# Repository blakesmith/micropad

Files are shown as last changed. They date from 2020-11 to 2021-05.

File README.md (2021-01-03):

# Micropad

This is a small macropad keyboard I built, mostly for controlling my music while working.

It includes:

- KiCAD schematic and PCB design.
- OpenSCAD case and top plate designs.
- Custom Rust firmware for the STM32F042 microcontroller
- Bill of materials, of all the components used.

License: MIT

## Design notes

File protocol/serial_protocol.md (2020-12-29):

# Micropad Serial Protocol

The micropad serial protocol is a simple byte-oriented format to
cotrol and configure the micropad from the connected host computer. It
uses a standard USB-CDC communication driver.

The first byte indicates the message type, followed by message
arguments. Successful responses return a 0 byte, error codes
non-zero. All message frames (requests and responses) are 8 byte aligned (64 bit frames).

Responses contain a response code in the first byte of the message
frame. Responses can also contain response arguments in the message
frame bytes, following the response code. The basic response codes
are:

0x00: Success.

0x80: Success, with a continuation bit set. The micropad will send
this response code when it has more response frames to send
callers. Callers continue to read message frames until either a
success response without the continuation bit set (0x00), or another
error value.

0x04: Not found.

## Message Types

### 0x01 - Ping

*Description*: Ping the micropad.
*Arguments*: No arguments.
*Valid responses*

- 0: Success

### 0x02 - Get Version

*Description*: Get the current firmware version
*Arguments*: No arguments.
*Valid responses*

- 0: Success, with follow on response bytes.
  - Byte 2: Major version. 0x00 - 0xFF.
  - Byte 3: Minor version. 0x00 - 0xFF.
  - Byte 4: Patch version. 0x00 - 0xFF.

### 0x03 - Set LED pulse brightness

*Description*: Set the LED pulse brightness when keys are pressed
*Arguments*: 1 byte brightness level.

- Arg 1: Brightness level. 0x00 - 0xFF.

*Valid responses*

- 0: Success

### 0x04 - Get the LED pulse brightness

*Description*: Retrieve the LED pulse brightness when the keys are pressed.
*Arguments*: No arguments.

*Valid responses*

- 0: Success, with follow on response bytes.
  - Byte 2: The current brightness level. 0x00 - 0xFF.

### 0x05 - Get current mode information

*Description*: Retrieve information about the mode.
*Arguments*: No arguments.
*Valid Responses*:

- 0: Success, with follow on response bytes.
  - Byte 2: Built in mode count.
  - Byte 3: User configurable mode count.
  - Byte 4: Current mode index. Enumeration starts at index 0, indexing the built-in modes first, followed by all the user modes. For example, if the built-in mode count is 2, and the user configurable mode count is 1, indices 0-1 would be built-in modes, and index 2 would be the user configurable mode.

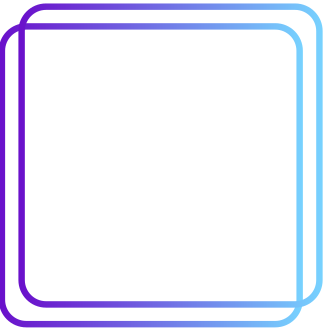
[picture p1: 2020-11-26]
square_only.png

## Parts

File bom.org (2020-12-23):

#+TITLE: Micropad Bill of Materials

| Name                              | Quantity | Part Number      | Price   | Link                                                                                                                                                                   |
|-----------------------------------+----------+------------------+---------+------------------------------------------------------------------------------------------------------------------------------------------------------------------------|
| STM32F042K6U6                     |        1 | C110616          | $2.72   | https://lcsc.com/product-detail/ST-Microelectronics_STMicroelectronics_STM32F042K6U6_STM32F042K6U6_C110616.html                                                        |
| 0603 2.5A fus                     |        1 | C311073          | $0.03   | https://lcsc.com/product-detail/Surface-Mount-Fuses_AEM_T0603HI3500TM_AEM-T0603HI3500TM_C311073.html                                                                   |
| Cherry MX Switches                |        3 |                  |         |                                                                                                                                                                        |
| LD1117-3.3                        |        1 | C347229          | $0.04   | https://lcsc.com/product-detail/Dropout-Regulators-LDO_UMW-Youtai-Semiconductor-Co-Ltd-LD1117-3-3_C347229.html                                                         |
| LED 0805                          |        2 | C601702          | $0.02   | https://lcsc.com/product-detail/Light-Emitting-Diodes-LED_TOGIALED-TJ-S2012CY8T5ALC6B-A5_C601702.html                                                                  |
| 100 ohm 0805                      |        2 | C17408           | $0.002  | https://lcsc.com/product-detail/Chip-Resistor-Surface-Mount_UNI-ROYAL-Uniroyal-Elec-0805W8F1000T5E_C17408.html                                                         |
| USB Micro B Connector             |        1 | C397452          | $0.02   | https://lcsc.com/product-detail/USB-Connectors_XKB-Connectivity-U254-051T-4BH83-F1S_C397452.html                                                                       |
| PEC11R-4015F-S0024 Rotary Encoder |        1 | C143789          | $1.78   | https://lcsc.com/product-detail/Coded-Rotary-Switches_BOURNS_PEC11R-4015F-S0024_PEC11R-4015F-S0024_C143789.html                                                        |
| 0.1uF SMD 0805 Cap                |        3 | C49678           | $0.0051 | https://lcsc.com/product-detail/Multilayer-Ceramic-Capacitors-MLCC-SMD-SMT_100nF-104-10-50V_C49678.html                                                                |
| 4.7uF SMD 0805 Cap                |        1 | C92762           | $0.026  | https://lcsc.com/product-detail/Multilayer-Ceramic-Capacitors-MLCC-SMD-SMT_TAIYO-YUDEN_EMK212B7475KG-T_4-7uF-475-10-16V_C92762.html                                    |
| 0.01uf SMD 0805 Cap               |        2 | C83170           | $0.0045 | https://lcsc.com/product-detail/Multilayer-Ceramic-Capacitors-MLCC-SMD-SMT_10nF-103-10-50V_C83170.html                                                                 |
| 10k 0805 Resistor                 |        5 | C115295          | $0.0015 | https://lcsc.com/product-detail/Chip-Resistor-Surface-Mount_FH-Guangdong-Fenghua-Advanced-Tech-RS-05K103JT_C115295.html                                                |
| 5.1k 0805 Resistor                |        2 | 311-5.10KCRCT-ND | $0.10   | https://www.digikey.com/en/products/detail/yageo/RC0805FR-075K1L/727988                                                                                                |
| APA102 DotStar RGB LED            |        1 | 2343             | $0.45   | https://www.digikey.com/en/products/detail/adafruit-industries-llc/2343/5761204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                                             |
| Encoder Knob                      |        1 | 1568-1600-ND     | $1.50   | https://www.digikey.com/en/products/detail/sparkfun-electronics/COM-10001/7229870                                                                                      |
| M3 8mm length standoff            |        4 | 732-12828-ND     | $0.40   | https://www.amazon.com/100Pcs-Female-Threaded-Standoff-Spacer/dp/B071VLNK37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          |
| M3 5mm male-female standoff       |        4 |                  |         | https://www.amazon.com/Antrader-Female-Thread-Standoff-100-Pack/dp/B07K67LVFR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 |
| USB-C Connector                   |        1 | WM12856CT-ND     | $2.19   | https://www.digikey.com/en/products/detail/molex/1054500101/5843890                                                                                                    |
|-----------------------------------+----------+------------------+---------+------------------------------------------------------------------------------------------------------------------------------------------------------------------------|

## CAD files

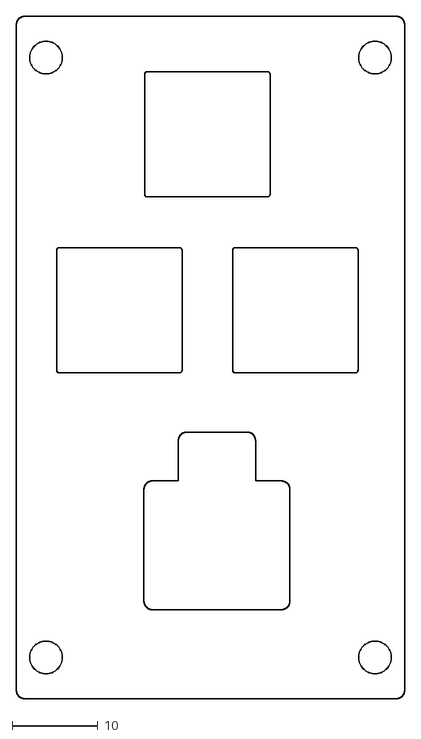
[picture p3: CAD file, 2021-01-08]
hardware/top_plate.dxf
45.2 x 79.5

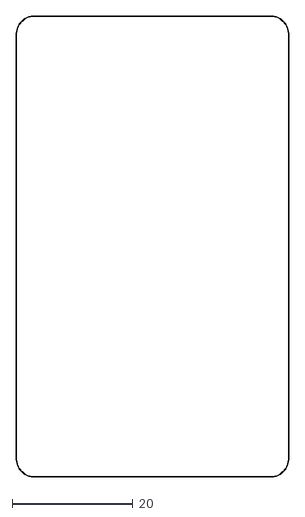
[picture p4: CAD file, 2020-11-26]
hardware/board_outline.dxf
45.1 x 76.5

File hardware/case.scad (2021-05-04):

$fn = 100;

module actual_pcb_board_outline() {
    rotate(a=180) {
        translate([0, 0])
            linear_extrude(height=10)
            import(file = "micropad/micropad-brd.svg", center=true);
    }
}

//actual_pcb_board_outline();

total_1u_count = 2;
row_count = 2;

switch_cutout_1u_width = 14.0;
switch_cutout_1u_length = 14.0;
switch_cutout_1u_padding = 6.50;
switch_cutout_1u_pitch = switch_cutout_1u_width + switch_cutout_1u_padding;

top_plate_padding_top_bottom = 0;
top_plate_padding_left_right = 0;
top_plate_height = 1.5;
top_plate_width = (((row_count * switch_cutout_1u_pitch) + top_plate_padding_top_bottom) * 1.854) + 1.5;
top_plate_length = (((total_1u_count * switch_cutout_1u_pitch) + top_plate_padding_left_right) * 1.03) + 1.0;
top_plate_corner_radius = 3;

echo("Top plate dimensions are w=", top_plate_width, ",l=", top_plate_length);

cherry_top_height = 3.6;
cherry_middle_height = 6.6;
cherry_bottom_width = 15.6;
cherry_bottom_length = 15.6;

dsa_keycap_bottom_width = 18.415;
dsa_keycap_bottom_length = 18.415;
dsa_keycap_top_length = 12.7;
dsa_keycap_top_width = 12.7;
dsa_keycap_height = 7.39;

encoder_width = 13;
encoder_length = 15;

encoder_base_height = 6.75;
encoder_shaft_height = 15.591;
encoder_shaft_diameter = 6.0;

apa102_length = 7;
apa102_width = 5;

usb_width = 9;
usb_length = 10.1;
usb_height = 4.56;

mounting_hole_radius = 1.5 + 0.4;
mounting_hole_head_radius = mounting_hole_radius + 0.8;
mounting_hole_head_height = 1.72;

mounting_hole_x_offset = 67.87 / 2; // Measured from the PCB directly
mounting_hole_y_offset = 36.33 / 2; // Measured form the PCB directly

pcb_width = 76.4;
pcb_length = 45.13;
pcb_height = 1.6;

standoff_radius = 2;
standoff_height = 8;

plate_standoff_radius = 2;
plate_standoff_height = 5;

case_chamfer_size = 2;
case_wall_thickness = 2;
case_length = pcb_length;
case_width = pcb_width + 3.2;

case_height = standoff_height + pcb_height + top_plate_height + (case_wall_thickness / 2) + plate_standoff_height - (case_chamfer_size / 2) + 5;

echo("Case height is: ", case_height);

standoff_offset_z = (case_height / 2) - (case_wall_thickness / 2);
pcb_offset_z = -standoff_offset_z + standoff_height;
plate_standoff_offset_z = pcb_offset_z + pcb_height;
top_plate_offset_z = plate_standoff_offset_z + plate_standoff_height;

echo("Top plate PCB distance is: ", top_plate_offset_z - pcb_offset_z);

encoder_offset_x = 0;
encoder_offset_y = -(top_plate_width / 2 / 2);
encoder_offset_z = pcb_offset_z + (encoder_base_height / 2) + pcb_height;

knob_radius = 12;
knob_height = 14;

MUTE_PALLETTE = [
    [39, 86, 123],
    [182, 59, 59],
    [249, 196, 20]
];

KEYCAP_PALLETTE = MUTE_PALLETTE;

C1 = [KEYCAP_PALLETTE[0][0] / 255, KEYCAP_PALLETTE[0][1] / 255, KEYCAP_PALLETTE[0][2] / 255];
C2 = [KEYCAP_PALLETTE[1][0] / 255, KEYCAP_PALLETTE[1][1] / 255, KEYCAP_PALLETTE[1][2] / 255];
C3 = [KEYCAP_PALLETTE[2][0] / 255, KEYCAP_PALLETTE[2][1] / 255, KEYCAP_PALLETTE[2][2] / 255];

KEYCAP_COLORS = [
    [C1, C1],
    [C1, C1],
];

union() {
//    pcb();
//    top_plate(top_plate_height);
    case();
//    plate(top_plate_length, top_plate_width, top_plate_corner_radius);
}

module pcb() {
    color("green") {
        translate([0, 0, pcb_offset_z]) {
            linear_extrude(height=pcb_height) {
                difference() {
                    plate(top_plate_length, top_plate_width, 0);
                    mounting_holes();
                }
            }
        }
    }
}

module top_plate(height=0) {
    translate([0, 0, top_plate_offset_z]) {
//        linear_extrude(height=height) {
            difference() {
                plate(top_plate_length, top_plate_width);
                union() {
                    translate([0.75, -2.5]) {
                        row_0_switch_cutout();
                        row_1_switch_cutout();
                        encoder_cutout();
                        apa102_cutout();
                    }
                    mounting_holes();
                }
            }
//        }
    }
}

module case() {
    module main_cutout() {
        translate([0, 0, case_wall_thickness]) {
            hull() {
                cube([case_length - case_wall_thickness,
                      case_width - case_wall_thickness,
                      case_height - case_wall_thickness], center=true);
                3d_rounded_corners(length=case_length - case_wall_thickness - (case_chamfer_size / 2),
                                   width=case_width - case_wall_thickness - (case_chamfer_size / 2),
                                   height=case_height - case_wall_thickness, corner_radius=2);
            }
        }
    }

    module usb_case_cutout() {
        height = usb_height + 3.0;
        translate([0, -(top_plate_width / 2) - 5, pcb_offset_z + (height / 2) + (pcb_height + 0.2)]) {
            hull() {
                cube([usb_length, usb_width, height], center=true);
                3d_rounded_corners(usb_length, usb_width, height, corner_radius=1);
            }
        }
    }

    difference() {
        //color("cyan")
            hull() {
                cube([case_length, case_width, case_height], center=true);
                3d_rounded_corners(length=case_length, width=case_width, height=case_height - case_chamfer_size, corner_radius=2);
            }
        union() {
            main_cutout();
            usb_case_cutout();
            translate([0, 0, -(case_height / 2) - 0.1]) {
                linear_extrude(height = mounting_hole_head_height) {
                    mounting_holes(radius = mounting_hole_head_radius);
                }
            }
            translate([0, 0, -(case_height / 2) - (standoff_height / 3)]) {
                linear_extrude(height = standoff_height * 2) {
                    mounting_holes(radius = mounting_hole_radius);
                }
            }
        }
    }
//    standoffs();
//    encoder();
}

module encoder() {
    top_of_encoder_base = encoder_offset_z + (encoder_base_height / 2);
    encoder_shaft_height_offset = top_of_encoder_base + (encoder_shaft_height / 2);

    module encoder_base() {
        translate([0, 0, encoder_offset_z]) {
            color("red")
                rotate(90)
                cube([encoder_width,
                      encoder_length,
                      encoder_base_height],
                     center=true);
        }
    }

    module encoder_shaft() {
        translate([0, 0, encoder_shaft_height_offset]) {
            color("blue")
                cylinder(h=encoder_shaft_height,
                         d=encoder_shaft_diameter,
                         center=true);
        }
    }

    module knob() {
        translate([0, 0, encoder_shaft_height_offset - (knob_height / 3)]) {
            color("silver")
                cylinder(r=knob_radius, h=knob_height);
        }
    }

    translate([0, encoder_offset_y]) {
        encoder_base();
        encoder_shaft();
        knob();
    }
}

module encoder_cutout() {
    translate([0, encoder_offset_y])
        hull() {
        square([encoder_length+2, encoder_width], center=true);
        rounded_corners(encoder_length, encoder_width, 1);
    }
}

module apa102_cutout() {
    translate([0, -(top_plate_width / 2 / 2 / 2)])
        hull() {
        square([apa102_length, apa102_width], center=true);
        rounded_corners(apa102_length, apa102_width, 1);
    }
}

module standoffs() {
    // Lower standoff
    translate([0, 0, -standoff_offset_z]) {
        translate([-mounting_hole_y_offset, -mounting_hole_x_offset])
            cylinder(r=standoff_radius, h=standoff_height);
        translate([mounting_hole_y_offset, -mounting_hole_x_offset])
            cylinder(r=standoff_radius, h=standoff_height);
        translate([mounting_hole_y_offset, mounting_hole_x_offset])
            cylinder(r=standoff_radius, h=standoff_height);
        translate([-mounting_hole_y_offset, mounting_hole_x_offset])
            cylinder(r=standoff_radius, h=standoff_height);
    }

    // Middle standoff
    translate([0, 0, plate_standoff_offset_z]) {
        translate([-mounting_hole_y_offset, -mounting_hole_x_offset])
            cylinder(r=plate_standoff_radius, h=plate_standoff_height);
        translate([mounting_hole_y_offset, -mounting_hole_x_offset])
            cylinder(r=plate_standoff_radius, h=plate_standoff_height);
        translate([mounting_hole_y_offset, mounting_hole_x_offset])
            cylinder(r=plate_standoff_radius, h=plate_standoff_height);
        translate([-mounting_hole_y_offset, mounting_hole_x_offset])
            cylinder(r=plate_standoff_radius, h=plate_standoff_height);
    }
}
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

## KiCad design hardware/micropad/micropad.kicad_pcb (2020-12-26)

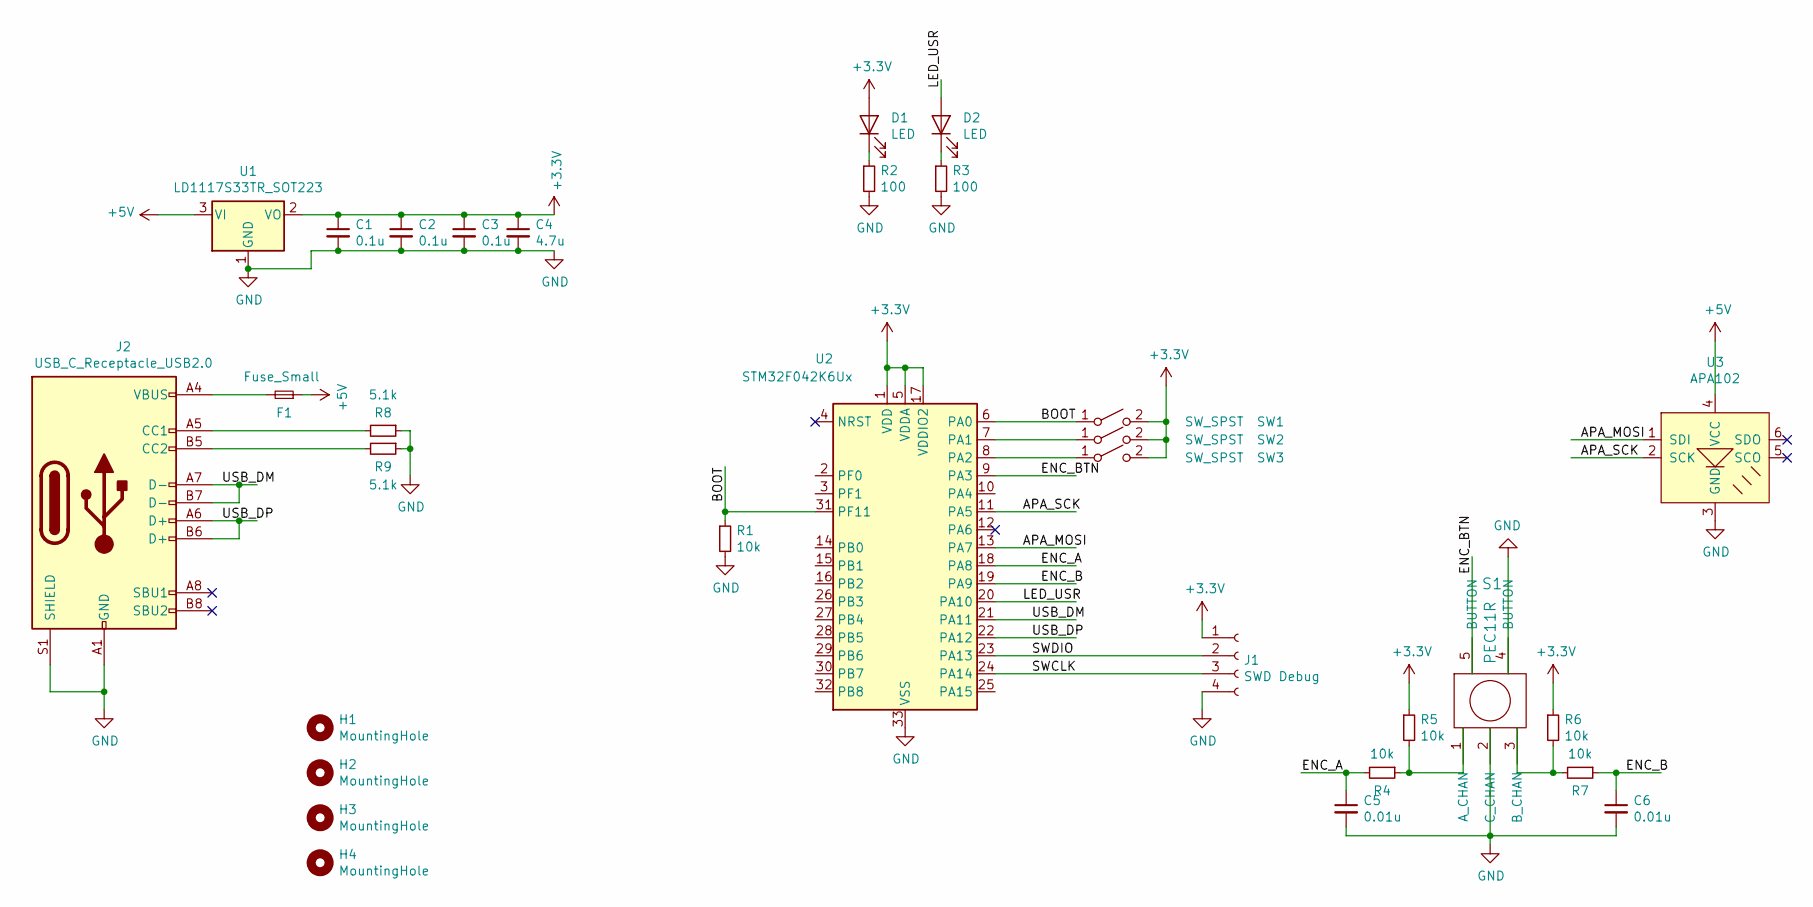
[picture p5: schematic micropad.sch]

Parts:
C1, C2, C3: 0.1u; C_0805
C4: 4.7u; C_0805
C5, C6: 0.01u; C_0805
D1, D2: LED; LED_0805
F1: Fuse_Small; C_0603
H1, H2, H3, H4: MountingHole; MountingHole_3.2mm_M3_ISO7380_Pad
J1: SWD Debug; REDFIT_IDC_SKEDD_CONN_4PIN
J2: USB_C_Receptacle_USB2.0; USB_C_Receptacle_Molex_1054500101
R1, R4, R5, R6, R7: 10k; R_0805
R2, R3: 100; R_0805
R8, R9: 5.1k; R_0805
S1: PEC11R; PEC11
SW1: SW_SPST; SW_Cherry_MX1A_2.00u_Plate
SW2, SW3: SW_SPST; SW_Cherry_MX1A_1.00u_Plate
U1: LD1117S33TR_SOT223; SOT-223
U2: STM32F042K6Ux; QFN-32-1EP_5x5mm_Pitch0.5mm
U3: APA102; LED_RGB_5050-6

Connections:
+3V3: C1.1, C2.1, C3.1, C4.1, D1.2 (A), J1.1, R5.1, R6.1, SW1.2 (B), SW2.2 (B), SW3.2 (B), U1.2 (VO), U2.1 (VDD), U2.5 (VDDA), U2.17 (VDDIO2)
+5V: F1.1, U1.3 (VI), U3.4 (VCC)
/APA_MOSI: U2.13 (PA7), U3.1 (SDI)
/APA_SCK: U2.11 (PA5), U3.2 (SCK)
/BOOT: R1.1, SW1.1 (A), U2.6 (PA0), U2.31 (PF11)
/ENC_A: C5.1, R4.2, U2.18 (PA8)
/ENC_B: C6.1, R7.1, U2.19 (PA9)
/ENC_BTN: S1.5 (BUTTON), U2.9 (PA3)
/LED_USR: D2.2 (A), U2.20 (PA10)
/SWCLK: J1.3, U2.24 (PA14)
/SWDIO: J1.2, U2.23 (PA13)
/USB_DM: J2.A7 (D-), J2.B7 (D-), U2.21 (PA11)
/USB_DP: J2.A6 (D+), J2.B6 (D+), U2.22 (PA12)
GND: C1.2, C2.2, C3.2, C4.2, C5.2, C6.2, J1.4, J2.A1 (GND), J2.A12 (GND), J2.B1 (GND), J2.B12 (GND), J2.S1 (SHIELD), R1.2, R2.2, R3.2, R8.1, R9.1, S1.2 (C_CHAN), S1.4 (BUTTON), U1.1 (GND), U2.33 (VSS), U3.3 (GND)
unnamed: D1.1 (K), R2.1
unnamed: D2.1 (K), R3.1
unnamed: F1.2, J2.A4 (VBUS), J2.A9 (VBUS), J2.B4 (VBUS), J2.B9 (VBUS)
unnamed: J2.A5 (CC1), R8.2
unnamed: J2.B5 (CC2), R9.2
unnamed: R4.1, R5.2, S1.1 (A_CHAN)
unnamed: R6.2, R7.2, S1.3 (B_CHAN)
unnamed: SW2.1 (A), U2.7 (PA1)
unnamed: SW3.1 (A), U2.8 (PA2)

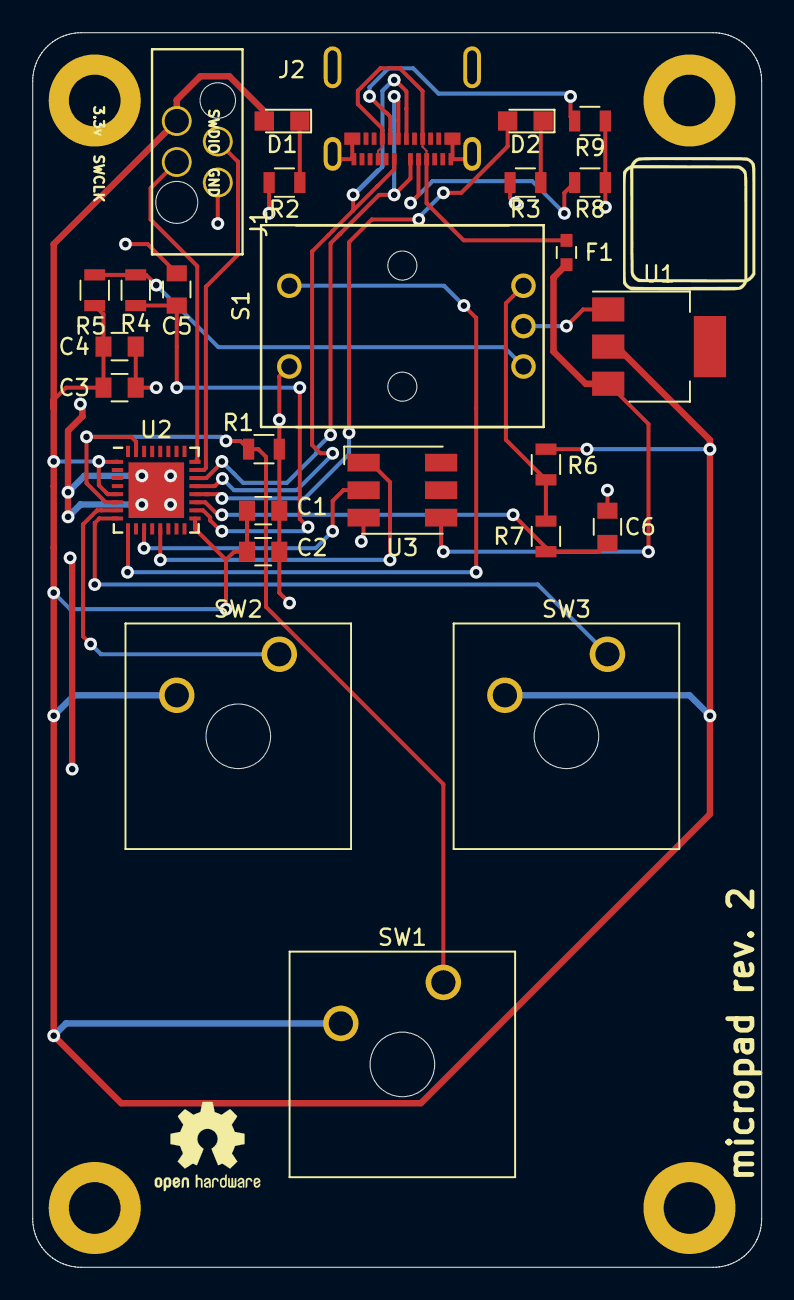
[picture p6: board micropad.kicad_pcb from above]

Board: 2 copper layers, 45.1 x 76.5 mm, 31 parts (0 on the bottom side), 23 nets.

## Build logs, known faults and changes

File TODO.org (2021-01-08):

#+TITLE: Micropad Todo List

* DONE Design CNC case
** DONE Add in tolerance for tallest PCB component?
* DONE Validate encoder shaft diameter
* DONE Replace JTAG connector with pin header holes
  - 4-pin connector: https://www.digikey.com/en/products/detail/w-rth-elektronik/490107670412/7917216
* DONE Validate mounting hole sizes
* DONE Name and logo
* DONE Research black magic probe and connectors
* DONE Validate boot pin button
* DONE Order boards and components
* DONE Test top plate fitting
* DONE Order top plate
* DONE Order 3D printed / CNC case
* DONE Update PCB to USB-C
** DONE Case cutout
* DONE Add additional ground connections to stm32
* DONE Change to M3 mounting holes
** DONE Case
** DONE PCB
* DONE Solve top plate spacing issue
  - 5mm bottom switch to plate height, 1.5mm top plate thickness
** TODO Case height
* DONE Order rev. 2 components 
  - USB C connectors
  - 5.1k resistors
  - Gateron blues
* DONE Order rev. 2 of PCBs (gold plating!)
** DONE Double check mounting hole alignment
* DONE DFU firmware update prototype
* DONE Multiple modes
* DONE Order rev. 2 of case and top plate
* DONE Order keycaps
* TODO Easy, in the field DFU updates?

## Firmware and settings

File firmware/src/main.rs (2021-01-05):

#![no_main]
#![no_std]

pub mod encoder;
pub mod hid;

use apa102_spi::{Apa102, PixelOrder};
use embedded_hal::serial::{Read, Write};
use encoder::RotaryEncoder;
use micropad_protocol::{Message, MessageFrame, ResponseCode, ResponsePayload};
use smart_leds::{gamma, SmartLedsWrite};
use smart_leds_trait::RGB8;

use panic_halt as _;

use stm32f0xx_hal as hal;

use hal::{
    delay::Delay,
    gpio::{
        gpioa::{PA0, PA1, PA10, PA2, PA3, PA5, PA6, PA7, PA8, PA9},
        Alternate, Floating, Input, Output, PullDown, PullUp, PushPull, AF0,
    },
    pac,
    pac::{interrupt, Interrupt},
    prelude::*,
    spi,
    usb::UsbBus,
};

use usb_device::bus::UsbBusAllocator;
use usb_device::prelude::*;
use usbd_serial::SerialPort;

use core::{cell::RefCell, ops::DerefMut};
use cortex_m::{interrupt::free as disable_interrupts, interrupt::Mutex, peripheral::NVIC};
use cortex_m_rt::entry;

use crate::hid::{Key, KeyboardHidClass, MediaCode, ScanCode};

const MAJOR_VERSION: u8 = 0;
const MINOR_VERSION: u8 = 1;
const PATCH_VERSION: u8 = 0;

static mut USB_BUS_ALLOC: Option<UsbBusAllocator<UsbBus<hal::usb::Peripheral>>> = None;
static USB_DEV: Mutex<RefCell<Option<UsbDevice<UsbBus<hal::usb::Peripheral>>>>> =
    Mutex::new(RefCell::new(None));
static USB_KEYBOARD: Mutex<RefCell<Option<KeyboardHidClass<UsbBus<hal::usb::Peripheral>>>>> =
    Mutex::new(RefCell::new(None));
static USB_SERIAL: Mutex<RefCell<Option<SerialPort<UsbBus<hal::usb::Peripheral>>>>> =
    Mutex::new(RefCell::new(None));

type Mode = [Key; 5];

static MUSIC_MODE: Mode = [
    Key::Media(MediaCode::VolumeUp),
    Key::Media(MediaCode::VolumeDown),
    Key::Media(MediaCode::PlayPause),
    Key::Media(MediaCode::ScanNext),
    Key::Media(MediaCode::ScanPrev),
];

static NAV_MODE: Mode = [
    Key::Normal(ScanCode::DownArrow),
    Key::Normal(ScanCode::UpArrow),
    Key::Normal(ScanCode::Return),
    Key::Normal(ScanCode::RightArrow),
    Key::Normal(ScanCode::LeftArrow),
];

static MODES: [&'static Mode; 2] = [&MUSIC_MODE, &NAV_MODE];

static CONTROL_STATE: Mutex<RefCell<ControlState>> = Mutex::new(RefCell::new(ControlState {
    led_brightness: 127,
    mode_index: 0,
}));

struct Devices {
    ok_led: PA10<Output<PushPull>>,
    delay: Delay,
    play_pause: PA0<Input<PullDown>>,
    next: PA2<Input<PullDown>>,
    prev: PA1<Input<PullDown>>,
    enc_btn: PA3<Input<PullUp>>,
    apa102: Apa102<
        spi::Spi<
            hal::stm32::SPI1,
            PA5<Alternate<AF0>>,
            PA6<Alternate<AF0>>,
            PA7<Alternate<AF0>>,
            spi::EightBit,
        >,
    >,
    encoder: RotaryEncoder<PA8<Input<Floating>>, PA9<Input<Floating>>>,
}

#[derive(Clone)]
struct ControlState {
    led_brightness: u8,
    mode_index: u8,
}

impl ControlState {
    fn set_led_brightness(&mut self, brightness: u8) {
        self.led_brightness = brightness;
    }

    fn get_led_brightness(&self) -> u8 {
        self.led_brightness
    }

    fn next_mode(&mut self) {
        self.mode_index = (self.mode_index + 1) % MODES.len() as u8;
    }

    fn get_mode_index(&self) -> u8 {
        self.mode_index
    }

    fn get_mode(&self) -> &'static Mode {
        MODES[self.mode_index as usize]
    }
}

struct LEDIndicatorState {
    color: RGB8,
    phase: u16,
}

impl LEDIndicatorState {
    fn new() -> Self {
        Self {
            color: RGB8 { r: 0, g: 0, b: 0 },
            phase: 0,
        }
    }

    fn pulse_color(&mut self, color: RGB8, brightness: u8) {
        self.color = color;
        self.phase = (brightness as u16) << 8;
    }

    fn write_if_blinking(
        &mut self,
        apa102: &mut Apa102<
            spi::Spi<
                hal::stm32::SPI1,
                PA5<Alternate<AF0>>,
                PA6<Alternate<AF0>>,
                PA7<Alternate<AF0>>,
                spi::EightBit,
            >,
        >,
    ) {
        if self.phase > 0 {
            self.phase -= 10;
            if self.color.r != 0 {
                self.color.r = (self.phase >> 8) as u8;
            };
            if self.color.g != 0 {
                self.color.g = (self.phase >> 8) as u8;
            };
            if self.color.b != 0 {
                self.color.b = (self.phase >> 8) as u8;
            };
            apa102.write(gamma([self.color].iter().cloned())).unwrap();
        }
    }
}

fn setup() -> Devices {
    let mut peripherals = pac::Peripherals::take().unwrap();
    let mut core = pac::CorePeripherals::take().unwrap();
    disable_interrupts(|cs| {
        let mut rcc = peripherals
            .RCC
            .configure()
            .hsi48()
            .enable_crs(peripherals.CRS)
            .sysclk(48.mhz())
            .pclk(24.mhz())
            .freeze(&mut peripherals.FLASH);

        let gpioa = peripherals.GPIOA.split(&mut rcc);
        let (
            play_pause,
            prev,
            next,
            enc_btn,
            enc_cw,
            enc_ccw,
            mut ok_led,
            sck,
            miso,
            mosi,
            usb_dm,
            usb_dp,
        ) = (
            gpioa.pa0.into_pull_down_input(cs), // Play pause button, has a 10k pull down resistor on the board
            gpioa.pa1.into_pull_down_input(cs), // Next button
            gpioa.pa2.into_pull_down_input(cs), // Prev button
            gpioa.pa3.into_pull_up_input(cs),   // Encoder button
            gpioa.pa8.into_floating_input(cs), // Encoder A, has a 10k pull up resistor on the board
            gpioa.pa9.into_floating_input(cs), // Encoder B, has a 10k pull up resistor on the board
            gpioa.pa10.into_push_pull_output(cs), // LED usr
            gpioa.pa5.into_alternate_af0(cs),  // APA102 SPI SCK
            gpioa.pa6.into_alternate_af0(cs),  // APA102 SPI MISO
            gpioa.pa7.into_alternate_af0(cs),  // APA102 SPI MOSI
            gpioa.pa11,                        // USB dm
            gpioa.pa12,                        // USB dp
        );
        let delay = Delay::new(core.SYST, &rcc);
        let spi = spi::Spi::spi1(
            peripherals.SPI1,
            (sck, miso, mosi),
            spi::Mode {
                polarity: spi::Polarity::IdleLow,
                phase: spi::Phase::CaptureOnFirstTransition,
            },
            1.mhz(),
            &mut rcc,
        );
        let apa102 = Apa102::new_with_options(spi, 4, true, PixelOrder::RBG);
        let encoder = RotaryEncoder::new(enc_cw, enc_ccw);
        let usb = hal::usb::Peripheral {
            usb: peripherals.USB,
            pin_dm: usb_dm,
            pin_dp: usb_dp,
        };

        unsafe {
            let bus_allocator = {
                USB_BUS_ALLOC = Some(UsbBus::new(usb));
                USB_BUS_ALLOC.as_ref().unwrap()
            };
            *USB_KEYBOARD.borrow(cs).borrow_mut() = Some(KeyboardHidClass::new(&bus_allocator));
            *USB_SERIAL.borrow(cs).borrow_mut() = Some(SerialPort::new(&bus_allocator));
            *USB_DEV.borrow(cs).borrow_mut() = Some(
                UsbDeviceBuilder::new(&bus_allocator, UsbVidPid(0xb38, 0x0003))
                    .manufacturer("micropad")
                    .product("micropad")
                    .serial_number("MP00X")
                    .max_packet_size_0(64)
                    .build(),
            );

            core.NVIC.set_priority(Interrupt::USB, 1);
            NVIC::unmask(Interrupt::USB);
        }

        ok_led.set_high().ok();
        Devices {
            ok_led,
            delay,
            play_pause,
            next,
            prev,
            enc_btn,
            apa102,
            encoder,
        }
    })
}

#[entry]
fn main() -> ! {
    let mut devices = setup();

    let led_color_reset: [RGB8; 1] = [RGB8 { r: 0, g: 0, b: 0 }];
    devices
        .apa102
        .write(led_color_reset.iter().cloned())
        .unwrap();

    let mut led_indicator = LEDIndicatorState::new();
    let mut current_encoder_count = 0;
    let mut key: Option<Key> = None;

    loop {
        let control_state = disable_interrupts(|cs| CONTROL_STATE.borrow(cs).borrow().clone());
        let current_mode = control_state.get_mode();

        // Sample encoder
        let encoder_sample: i32 = devices.encoder.read_count();
        let encoder_diff: i32 = encoder_sample - current_encoder_count;
        current_encoder_count = encoder_sample;

        // Encoder
        if encoder_diff > 0 {
            led_indicator.pulse_color(
                RGB8 {
                    r: 0,
                    b: 255,
                    g: 255,
                },
                control_state.get_led_brightness(),
            );
            key = Some(current_mode[0]);
        } else if encoder_diff < 0 {
            led_indicator.pulse_color(
                RGB8 {
                    r: 255,
                    b: 255,
                    g: 0,
                },
                control_state.get_led_brightness(),
            );
            key = Some(current_mode[1]);
        }
        // Buttons
        else if devices.play_pause.is_high().unwrap() {
            led_indicator.pulse_color(
                RGB8 { r: 0, g: 0, b: 255 },
                control_state.get_led_brightness(),
            );
            key = Some(current_mode[2]);
        } else if devices.next.is_high().unwrap() {
            led_indicator.pulse_color(
                RGB8 { r: 0, g: 255, b: 0 },
                control_state.get_led_brightness(),
            );
            key = Some(current_mode[3]);
        } else if devices.prev.is_high().unwrap() {
            led_indicator.pulse_color(
                RGB8 { r: 255, g: 0, b: 0 },
                control_state.get_led_brightness(),
            );
            key = Some(current_mode[4]);
        } else if devices.enc_btn.is_low().unwrap() {
            led_indicator.pulse_color(
                RGB8 {
                    r: 255,
                    g: 255,
                    b: 0,
                },
                control_state.get_led_brightness(),
            );
            key = None; // Switching modes, don't send a HID report.
            disable_interrupts(|cs| {
                CONTROL_STATE.borrow(cs).borrow_mut().next_mode();
            });
        } else {
            // Encoder diff is zero, and no buttons currently pressed. Reset report.
            key = None;
        }

        disable_interrupts(|cs| {
            if let &mut Some(ref mut keyboard) = USB_KEYBOARD.borrow(cs).borrow_mut().deref_mut() {
                match key {
                    Some(k) => keyboard.add_key(k),
                    None => keyboard.reset_report(),
                };

                keyboard.send_media_report_if_changed();
                keyboard.send_key_report_if_changed();
            }
        });

        led_indicator.write_if_blinking(&mut devices.apa102);

        // Make sure we delay outside of our 'disable_interrupts' block
        if key.is_some() {
            devices.delay.delay_ms(10u32);
        }
    }
}

fn read_into_frame<R>(frame: &mut MessageFrame, reader: &mut R) -> nb::Result<(), R::Error>
where
    R: Read<u8>,
{
    for i in 0..frame.frame_size() {
        match reader.read() {
            Ok(b) => frame.buf[i] = b,
            Err(err) => return Err(err),
        }
    }

    Ok(())
}

fn write_response<W>(
    frame: &mut MessageFrame,
    writer: &mut W,
    code: ResponseCode,
) -> nb::Result<(), W::Error>
where
    W: Write<u8>,
{
    write_response_payload(frame, writer, code, &ResponsePayload::None)
}

fn write_response_payload<W>(
    frame: &mut MessageFrame,
    writer: &mut W,
    code: ResponseCode,
    payload: &ResponsePayload,
) -> nb::Result<(), W::Error>
where
    W: Write<u8>,
{
    frame.buf[0] = code.raw();
    payload.fill(frame);

    for i in 0..frame.frame_size() {
        writer.write(frame.buf[i])?;
    }
    Ok(())
}

fn poll_usb() {
    disable_interrupts(|cs| {
        if let (&mut Some(ref mut device), &mut Some(ref mut keyboard), &mut Some(ref mut serial)) = (
            USB_DEV.borrow(cs).borrow_mut().deref_mut(),
            USB_KEYBOARD.borrow(cs).borrow_mut().deref_mut(),
            USB_SERIAL.borrow(cs).borrow_mut().deref_mut(),
        ) {
            device.poll(&mut [keyboard, serial]);
            let mut message_frame = MessageFrame::new();

            if let Ok(_) = read_into_frame(&mut message_frame, serial) {
                let message = Message::from(&message_frame);
                match message {
                    Message::Ping => {
                        let _ = write_response(&mut message_frame, serial, ResponseCode::Ok);
                    }
                    Message::SetLedBrightness(brightness) => {
                        CONTROL_STATE
                            .borrow(cs)
                            .borrow_mut()
                            .set_led_brightness(brightness);
                        let _ = write_response(&mut message_frame, serial, ResponseCode::Ok);
                    }
                    Message::GetLedBrightness => {
                        let brightness = CONTROL_STATE.borrow(cs).borrow().get_led_brightness();
                        let _ = write_response_payload(
                            &mut message_frame,
                            serial,
                            ResponseCode::Ok,
                            &ResponsePayload::LedBrightness(brightness),
                        );
                    }
                    Message::GetModeInfo => {
                        let current_mode = CONTROL_STATE.borrow(cs).borrow().get_mode_index();
                        let _ = write_response_payload(
                            &mut message_frame,
                            serial,
                            ResponseCode::Ok,
                            &ResponsePayload::ModeInfo {
                                built_in_mode_count: MODES.len() as u8,
                                user_mode_count: 0,
                                current_mode_index: current_mode,
                            },
                        );
                    }
                    Message::GetVersion => {
                        let _ = write_response_payload(
                            &mut message_frame,
                            serial,
                            ResponseCode::Ok,
                            &ResponsePayload::Version {
                                major: MAJOR_VERSION,
                                minor: MINOR_VERSION,
                                patch: PATCH_VERSION,
                            },
                        );
                    }
                    _ => {
                        let _ = write_response(
                            &mut message_frame,
                            serial,
                            ResponseCode::UnknownMessage,
                        );
                    }
                };
            };
        }
    });
}

#[interrupt]
fn USB() {
    poll_usb();
}

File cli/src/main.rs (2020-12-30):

use clap::{App, Arg, SubCommand};
use log;
use log::LevelFilter;
use micropad_protocol::{Message, MessageFrame, ResponseCode, ResponsePayload};
use simple_logger::SimpleLogger;

use serialport::{SerialPort, SerialPortInfo, SerialPortType};
use std::time::Duration;

#[derive(Debug)]
enum CliError {
    Serial(serialport::Error),
    Io(std::io::Error),
    NotFound,
}

impl From<serialport::Error> for CliError {
    fn from(err: serialport::Error) -> CliError {
        CliError::Serial(err)
    }
}

impl From<std::io::Error> for CliError {
    fn from(err: std::io::Error) -> CliError {
        CliError::Io(err)
    }
}

fn find_micropads() -> Result<Box<dyn Iterator<Item = SerialPortInfo>>, CliError> {
    let available_ports = serialport::available_ports()?;
    Ok(Box::new(available_ports.into_iter().filter(
        |info| match info.port_type {
            SerialPortType::UsbPort(ref usb_port_info) => match usb_port_info.serial_number {
                Some(ref serial) if serial.starts_with("MP00") => true,
                _ => false,
            },
            _ => false,
        },
    )))
}

fn find_micropad(position: usize) -> Result<SerialPortInfo, CliError> {
    find_micropads()?
        .nth(position)
        .ok_or(CliError::NotFound)
        .map_err(|err| match err {
            CliError::NotFound => {
                log::error!(
                    "Could not find an attached micropad at position: {}, is it plugged in?",
                    position
                );
                CliError::NotFound
            }
            err => err,
        })
}

fn connect_micropad(port_info: &SerialPortInfo) -> Result<Box<dyn SerialPort>, CliError> {
    serialport::new(&port_info.port_name, 11520)
        .timeout(Duration::from_millis(500))
        .open()
        .map_err(|err| err.into())
}

fn send_message(message: &Message) -> Result<(ResponseCode, ResponsePayload), CliError> {
    let micropad_info = find_micropad(0)?;
    let mut micropad_port = connect_micropad(&micropad_info)?;

    let request_frame = MessageFrame::from(message);
    micropad_port.write_all(&request_frame.buf)?;

    let mut response_frame = MessageFrame::new();
    micropad_port.read_exact(&mut response_frame.buf)?;
    Ok(response_frame.into_code_and_payload(message))
}

fn ping() -> Result<(), CliError> {
    match send_message(&Message::Ping)? {
        (ResponseCode::Ok, _) => log::info!("Got ping response!"),
        response => log::error!("Got non-ok response: {:?}", response),
    }

    Ok(())
}

fn set_led_brightness(brightness: u8) -> Result<(), CliError> {
    match send_message(&Message::SetLedBrightness(brightness))? {
        (ResponseCode::Ok, _) => log::info!("LED brightness changed to: {}", brightness),
        response => log::error!("Got non-ok response: {:?}", response),
    }

    Ok(())
}

fn get_led_brightness() -> Result<(), CliError> {
    match send_message(&Message::GetLedBrightness)? {
        (ResponseCode::Ok, ResponsePayload::LedBrightness(brightness)) => {
            log::info!("Current LED brightness is: {}", brightness);
        }
        (response, _) => log::error!("Got non-ok response: {:?}", response),
    }

    Ok(())
}

fn get_version() -> Result<(), CliError> {
    match send_message(&Message::GetVersion)? {
        (
            ResponseCode::Ok,
            ResponsePayload::Version {
                major,
                minor,
                patch,
            },
        ) => {
            log::info!(
                "Current firmware version is is: {}.{}.{}",
                major,
                minor,
                patch
            );
        }
        (response, _) => log::error!("Got non-ok response: {:?}", response),
    }

    Ok(())
}

fn get_mode_info() -> Result<(), CliError> {
    match send_message(&Message::GetModeInfo)? {
        (
            ResponseCode::Ok,
            ResponsePayload::ModeInfo {
                built_in_mode_count,
                user_mode_count,
                current_mode_index,
            },
        ) => {
            log::info!("Built in mode count: {}", built_in_mode_count);
            log::info!("User mode count: {}", user_mode_count);
            log::info!("Current mode index: {}", current_mode_index);
        }
        (response, _) => log::error!("Got non-ok response: {:?}", response),
    }

    Ok(())
}

fn main() {
    let matches = App::new("Micropad cli interface")
        .version("0.1")
        .author("Blake Smith <blakesmith0@gmail.com>")
        .about("Control and configure your USB micropad via the command line")
        .arg(
            Arg::with_name("debug")
                .help("Enable debug logging")
                .short("d"),
        )
        .subcommand(
            SubCommand::with_name("ping").about("Ping the micropad to test for connectivity"),
        )
        .subcommand(
            SubCommand::with_name("set_led_brightness")
                .about("Set the LED brightness to 0-255")
                .arg(
                    Arg::with_name("brightness")
                        .short("b")
                        .required(true)
                        .takes_value(true)
                        .help("The LED brightness, 0 - 255"),
                ),
        )
        .subcommand(
            SubCommand::with_name("get_led_brightness").about("Get the current LED brightness"),
        )
        .subcommand(
            SubCommand::with_name("get_mode_info").about("Get the current mode information"),
        )
        .subcommand(SubCommand::with_name("get_version").about("Get the current firmware version"))
        .get_matches();

    if matches.is_present("debug") {
        SimpleLogger::new()
            .with_level(LevelFilter::Debug)
            .init()
            .unwrap();
    } else {
        SimpleLogger::new()
            .with_level(LevelFilter::Info)
            .init()
            .unwrap();
    }
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

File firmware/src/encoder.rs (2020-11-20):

use embedded_hal::digital::v2::InputPin;

#[derive(Copy, Clone)]
pub enum RotationAction {
    None,
    Clockwise,
    CounterClockwise,
}

/**
 * Computed from the quadrature output table. Algorithm is:
 * 1. Start with pin state 0b00 (both pins low)
 * 2. Moving through the table clockwise, shift the previous two bits twice. Append next bit state to the lower 2 bits of the 4-bit integer. These get assigned ENC_ACTION_ROTATE_CLOCKWISE
 * 3. Moving through the table counter clockwise, shift the previous two bits twice. Append next bit state to the lower 2 bits of the 4-bit integer. These get assigned ENC_ACTION_ROTATE_COUNTER_CLOCKWISE
 * 4. Go through each state in the table again, and repeat each state for the upper and lower bits of the 4-bit integer. These get assigned ENC_ACTION_NONE.
 * 5. Each bit state is equal to an integer between 0 - 15 (The array length of the table below), the value is the direction of the direction the state should move.
 * 6. Any gaps in the table get assigned a value of ENC_ACTION_NONE.
 */
static ENCODER_ACTIONS: &'static [RotationAction] = &[
    RotationAction::None,
    RotationAction::CounterClockwise,
    RotationAction::Clockwise,
    RotationAction::None,
    RotationAction::Clockwise,
    RotationAction::None,
    RotationAction::None,
    RotationAction::CounterClockwise,
    RotationAction::CounterClockwise,
    RotationAction::None,
    RotationAction::None,
    RotationAction::Clockwise,
    RotationAction::None,
    RotationAction::Clockwise,
    RotationAction::CounterClockwise,
    RotationAction::None,
];

pub struct RotaryEncoder<CwPin, CcwPin>
where
    CwPin: InputPin,
    CcwPin: InputPin,
{
    /// The current state of the encoder table
    rotation_state: u8,
    /// The rotation count of the encoder
    count: i32,
    clockwise_pin: CwPin,
    counter_clockwise_pin: CcwPin,
}

impl<CwPin, CcwPin> RotaryEncoder<CwPin, CcwPin>
where
    CwPin: InputPin,
    CcwPin: InputPin,
{
    pub fn new(clockwise_pin: CwPin, counter_clockwise_pin: CcwPin) -> Self {
        Self {
            rotation_state: 0,
            count: 0,
            clockwise_pin,
            counter_clockwise_pin,
        }
    }

    pub fn read_count(&mut self) -> i32 {
        self.count += match self.rotation_action() {
            RotationAction::None => 0,
            RotationAction::Clockwise => 1,
            RotationAction::CounterClockwise => -1,
        };
        self.count
    }

    fn rotation_action(&mut self) -> RotationAction {
        let cw_pin = self.clockwise_pin.is_high().map_or(0, |b| b as u8);
        let ccw_pin = self.counter_clockwise_pin.is_high().map_or(0, |b| b as u8);
        self.rotation_state <<= 2; // Retain the previous pin state as the upper two bits
        self.rotation_state |= ((cw_pin << 1) | ccw_pin) & 0x03; // Shift the current state onte the lower 2 bits
        let lookup_index = self.rotation_state & 0x0F; // Only keep the bottom 4 bits, throw away the upper 4, and lookup in our rotation table
        ENCODER_ACTIONS[lookup_index as usize]
    }
}

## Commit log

2020-11-12 Add initial bom
2020-11-12 Add initial schema, update bom
    [micropad.kicad_pcb, micropad.sch]
2020-11-12 Continue connecting peripherals to the microcontroller
    [micropad.sch]
2020-11-14 Add USB footprint
    [micropad.sch]
2020-11-15 Get PCB footprints to load
    [micropad.kicad_pcb, micropad.sch]
2020-11-16 Start init the usb device
2020-11-16 Wire in the keyboard to send play/pause
2020-11-16 Assign more pins
    [micropad.sch]
2020-11-16 Swap in an APA102 instead of the OLED screen
    [micropad.kicad_pcb, micropad.sch]
2020-11-16 Add next and prev button media keys
2020-11-17 Start placing preliminary components
    [micropad.kicad_pcb]
2020-11-17 Use a QFN32 package that's easier to work with
    [micropad.kicad_pcb, micropad.sch]
2020-11-17 Add mounting holes
    [micropad.kicad_pcb, micropad.sch]
2020-11-19 Route remaining tracks
    [micropad.kicad_pcb, micropad.sch]
2020-11-19 Add fuse, fixup DRC and labels
    [micropad.kicad_pcb, micropad.sch]
2020-11-19 Remove OLED screen, replace with APA102 LED
2020-11-20 Add initial rotary encoder port
2020-11-20 Integrate encoder into main loop
2020-11-20 Start initial plate in the case
    [case.scad]
2020-11-23 Start playing with top plate width
    [case.scad]
2020-11-23 Reduce board width
    [case.scad, micropad.kicad_pcb]
2020-11-23 Line up mounting holes
    [micropad.kicad_pcb]
2020-11-23 Line up mounting holes better and round PCB corners
    [case.scad, micropad.kicad_pcb]
2020-11-23 Update to plated mounting holes
    [micropad.kicad_pcb, micropad.sch]
2020-11-23 Minor USB and silk screen adjustments
    [micropad.kicad_pcb]
2020-11-24 Add initial encoder and apa cutouts
    [case.scad]
2020-11-24 Round more cutout corners
    [case.scad]
2020-11-24 Add usb cutout
    [case.scad]
2020-11-24 Adjust mounting hole sizes
    [case.scad, micropad.kicad_pcb]
2020-11-24 Add a possible encoder knob
2020-11-24 Case starting to come together
    [case.scad]
2020-11-25 Adjust switch placement, based on height
    [case.scad]
2020-11-25 Get standoffs lined up again
    [case.scad]
2020-11-25 Add bottom case mounting holes
    [case.scad]
2020-11-25 Add encoder model
    [case.scad]
2020-11-25 Add usb case cutout
    [case.scad]
2020-11-25 Color the case
    [case.scad]
2020-11-25 Add chamfer to outer case
    [case.scad]
2020-11-25 Add in some tolerances for the PCB and top plate
    [case.scad]
2020-11-25 Add some tolerance for the tallest PCB component
    [case.scad]
2020-11-25 Try a 6mm standoff
    [case.scad]
2020-11-26 Use temporary connector for SWD programming
    [micropad.kicad_pcb, micropad.sch]
2020-11-26 Add logo
    [micropad.kicad_pcb]
2020-11-26 Check in DXF files
    [board_outline.dxf, top_plate.dxf]
2020-11-26 Fixup DRC
    [micropad.kicad_pcb]
2020-11-26 Cleanup LED user track
    [micropad.kicad_pcb]
2020-11-26 Refill PCB
    [micropad.kicad_pcb]
2020-11-27 Order boards and components
    [micropad-B_Cu.gbr, micropad-B_Mask.gbr, micropad-B_Paste.gbr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]
2020-11-27 Switch the play_pause button to floating
2020-12-07 Make an indent for the mounting hole screws
    [case.scad]
2020-12-07 Make mounting hole indents screw head size accurate
    [case.scad]
2020-12-10 Get main media buttons working
2020-12-10 Start pulsing LED on button push
2020-12-10 Fix blue color phase shifting
    [main.rs]
2020-12-10 Toggle the LED when the encoder value changes
2020-12-10 Pulse the main indicator LED on volume adjustments
2020-12-10 Softer color pulses
    [case.scad]
2020-12-10 Encoder button mutes
2020-12-12 Minor top plate and case tweaks
    [case.scad, micropad.kicad_pcb, top_plate.dxf]
2020-12-12 Adjust the case width a bit more for tolerances
    [case.scad]
2020-12-12 Make encoder cutout a little bit bigger
    [case.scad]
2020-12-15 Add potential USB-C part
    [case.scad]
2020-12-16 Get USB serial and keyboard working on the same device
2020-12-16 Shorten interrupt disable window
    [main.rs]
2020-12-18 Add untested enabling / disabling RGB LED
2020-12-21 Enabling and disabling the LED is working
2020-12-22 Remove enable / disable LED messages, replace with set LED brightness
    [main.rs]
2020-12-22 Replace USB micro connector with USB-C connector
    [micropad.kicad_pcb, micropad.sch]
2020-12-22 Add additional ground connections to the STM32
    [micropad.kicad_pcb]
2020-12-22 Revision 2
    [micropad.kicad_pcb]
2020-12-23 Change PCB mounting holes to M3
    [micropad.kicad_pcb, micropad.sch]
2020-12-23 Adjust case / top plate mounting hole sizes and positions for M3 screws
    [case.scad]
2020-12-23 Adjust usb connector dimensions for USB-C
    [case.scad]
2020-12-23 Adjust heights for new set of standoffs
    [case.scad]
2020-12-23 Move usb cutout to just above the PCB
    [case.scad]
2020-12-23 Adjust switch cutout locations and tweak encoder cutout location
    [case.scad, top_plate.dxf]
2020-12-23 Make the PCB non rounded in modeling
    [case.scad]
2020-12-26 Order rev. 2 of PCB
    [micropad-B_Cu.gbr, micropad-B_Mask.gbr, micropad-B_Paste.gbr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]
2020-12-28 Send both report types, and swap modes on encoder press
    [main.rs]
2020-12-28 Replace second mode with keyboard nav mode
    [main.rs]
2020-12-28 Change message frame size to 8 bytes
2020-12-29 Add untested method to get the led brightness
2020-12-30 Make sure reads and writes transmit the entire frame before returning
2021-01-05 Fix: Correct frame sizing for longer frames
    [main.rs]
2021-01-08 Rev 2. of case and top plate
    [case.scad, top_plate.dxf]
2021-05-03 Case, rev 3
    [case.scad]
2021-05-03 Case, rev 4
    [case.scad]
2021-05-03 Case, rev 5
    [case.scad]
2021-05-03 Case, rev 6
    [case.scad]
2021-05-03 Wrong PCB height
    [case.scad]
2021-05-04 Case, rev 7
    [case.scad]
2021-05-04 Expand USB cutout more
    [case.scad]
